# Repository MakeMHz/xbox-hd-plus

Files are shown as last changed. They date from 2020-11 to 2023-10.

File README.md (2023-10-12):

<h1 align="center">
  <br>
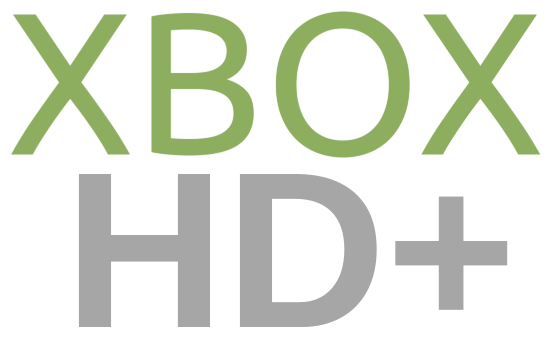
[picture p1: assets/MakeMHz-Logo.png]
XboxHD+
  
  <br>
</h1>
<h4 align="center">The first and only purely digital video output mod for the original Microsoft Xbox.</h4>
<p align="center">
 
 
 
 
</p>
<p align="center">
  <a href="#about">About</a> •
  <a href="#features">Features</a> •
  <a href="#installation">Installation</a> •
  <a href="#software">Software</a> •
  <a href="#hardware">Hardware</a> •
  <a href="#licensing">Licensing</a>
</p>

## About
The first and only purely digital video output mod for the original Microsoft Xbox. Video is captured directly off of the pixel data bus from the GPU, encoded, and sent directly to your HD TV with no added interpolation or frame-buffering for a crystal clear, no added lag, video output.

But pixel-perfect video isn't all the XboxHD+ offers. Audio is captured from the Xbox's digital SPDIF audio and output over the HDMI connector, and with the correct receiver allow for 5.1 Dolby Digital audio on select games.

XboxHD+ has been in development for over a year and fully tested on every board variation and revision.

## Features
XboxHD+ was designed from the ground up to be the best possible solution for your original Xbox.

  *  Pixel perfect digital video. Supports all official Xbox video resolutions. (480i, 480p, 576i, 720P, and 1080i)
  *  Crystal clear digital audio with surround-sound and Dolby Digital pass-through.
  *  Upgradable firmware via our Xbox application for additional future features, bug fixes, etc!
  *  HDMI CEC support.
  *  Completely reversible! 100% no-cut mod.
  *  Optional force 480P. (Force 480i games to run in 480p)
  *  Optional auto anamorphic widescreen for widescreen 480P content. By default, 16:9 480P content will be stretched to fullscreen as the game intended. Avoid the hassle of having to adjust your TV's zoom/aspect ratio when switch between widescreen and none-widescreen 480P games.

## Installation
**Stellar XboxHD+**

[Upgrading to Stellar XboxHD+](https://support.makemhz.com/xbox-hdmi/upgrade/stellar)

[Installation Manual (Stellar XboxHD+ v2 1.0 - 1.5)](https://support.makemhz.com/xbox-hdmi/installation/stellar-xboxhd-1-0)

[Installation Manual (Stellar XboxHD+ v2 1.6)](https://support.makemhz.com/xbox-hdmi/installation/stellar-xboxhd-1-6)

**XboxHD+**

[Installation Manual (XboxHD+ 1.0 - 1.5)](https://support.makemhz.com/xbox-hdmi/installation/xboxhd-1-0)

[Installation Manual (XboxHD+ 1.6)](https://support.makemhz.com/xbox-hdmi/installation/xboxhd-1-6)

**XboxHDMI**

[Installation Manual (XboxHDMI 1.0 - 1.5)](https://support.makemhz.com/xbox-hdmi/installation/xboxhdmi-1-0)

[Installation Manual (XboxHDMI 1.6)](https://support.makemhz.com/xbox-hdmi/installation/xboxhdmi-1-6)

## Software
Configuration and firmware updates are preformed using the XboxHD+ homebrew app. For Stellar XboxHD+ everything is handled via StellarOS.

See [MakeMHz/xbox-hd-plus-app](https://github.com/MakeMHz/xbox-hd-plus-app) (For XboxHD+ installs)

See [MakeMHz/xbox-hdmi-app](https://github.com/MakeMHz/xbox-hdmi-app) (For XboxHDMI installs)

## Hardware
### QSB Fix (1.0/1.1)
[KiCad Project](board/1_0_fix)

### 3D Printed Parts
The XboxHD+ kit includes two 3D printed parts. Parts are designed in Fusion360 and can be downloaded in multiple formats from the links below.

[HDMI Panel](https://raw.githubusercontent.com/MakeMHz/xbox-hd-plus/master/stl/Case%20Filler.stl)

[Board Spacer](https://raw.githubusercontent.com/MakeMHz/xbox-hd-plus/master/stl/Board%20Spacer.stl)

## Licensing
Parts of XboxHD+ are free and open source with plans to release everything else in the near future. Please respect the licenses available in their respective folders.

Hardware is shared under the CERN OHL version 1.2.
 
XboxHD+ configuration app was made with NXDK and is shared under GPLv2.

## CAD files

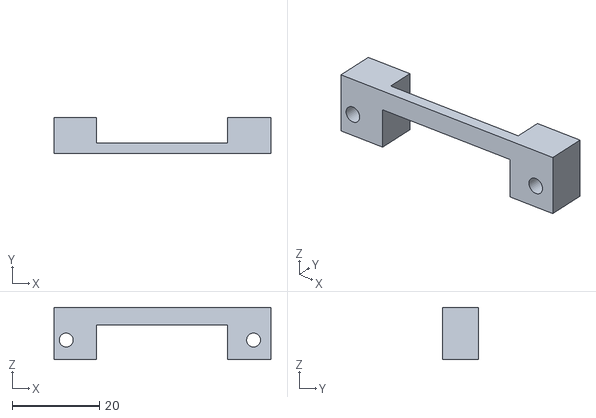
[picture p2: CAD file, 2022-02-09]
stl/Board Spacer.stl
49.8 x 8.20 x 12.0

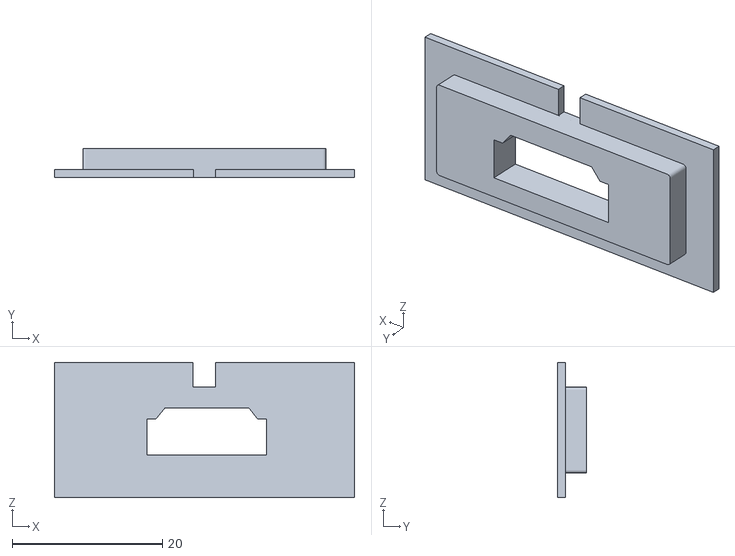
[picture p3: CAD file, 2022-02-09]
stl/Case Filler.stl
40.0 x 3.80 x 18.0

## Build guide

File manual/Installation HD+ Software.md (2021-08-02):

# Installation - XboxHD+ Software
This guide is for the installation of the XboxHD+ software and kernel patch.

## Checklist
- [ ] OpenXenium installed.
  - [ ] Tested and verified that OpenXenium is accessible via network. (Both HTTP and FTP)
- [ ] System is fully working.

### CONTACT SUPPORT IF YOU HAVE ANY QUESTIONS OR CONCERNS!

## Hard Drive Preparation

### Step 1:
Boot console to XeniumOS via the eject button.

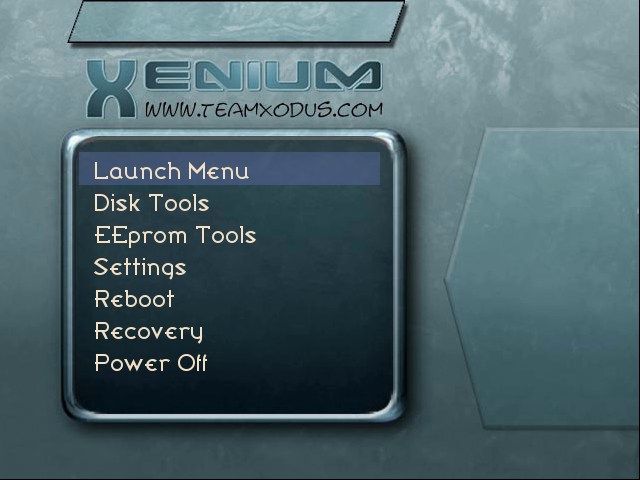
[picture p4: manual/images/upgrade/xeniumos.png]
XeniumOS Boot Screen


### Step 3:
Download the latest XboxHD+ app release.

[Latest Release](https://github.com/MakeMHz/xbox-hd-plus-app/releases/latest)

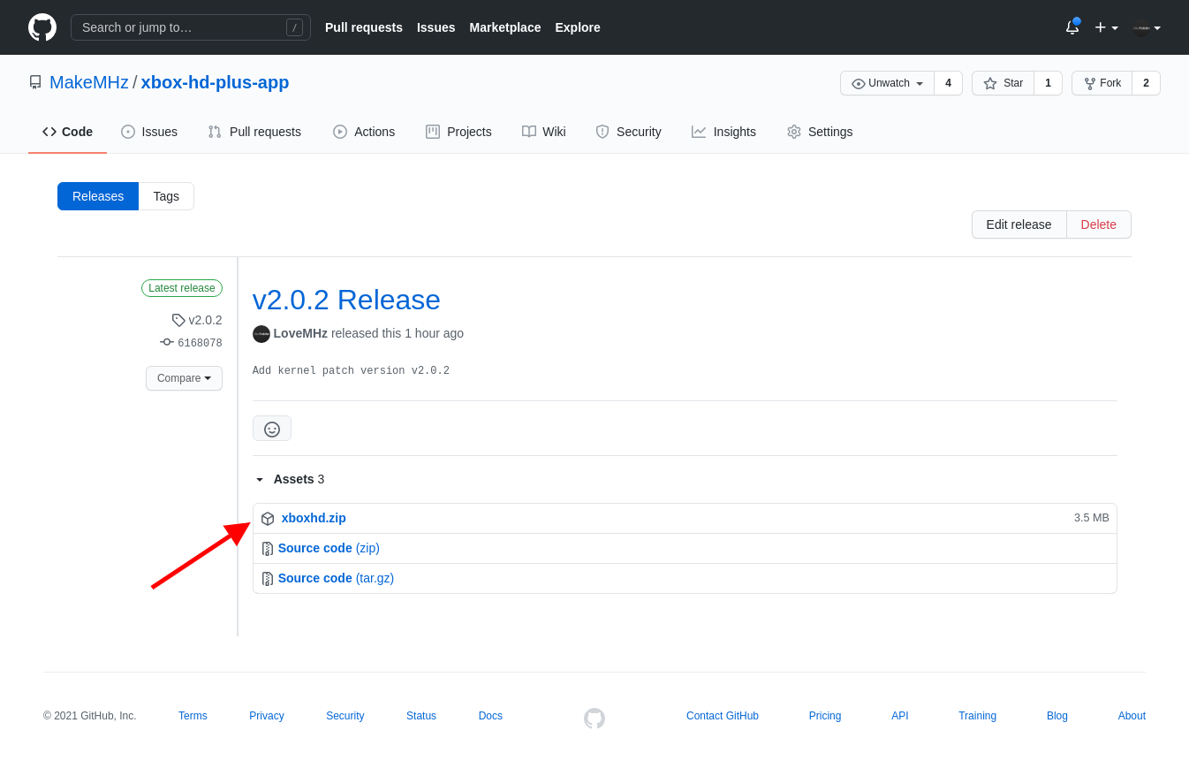
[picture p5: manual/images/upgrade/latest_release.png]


### Step 4:
Extract the files and FTP over contents to the C drive. Files must be placed on the C drive. (Inside of a folder called 'xboxhd' as shown)

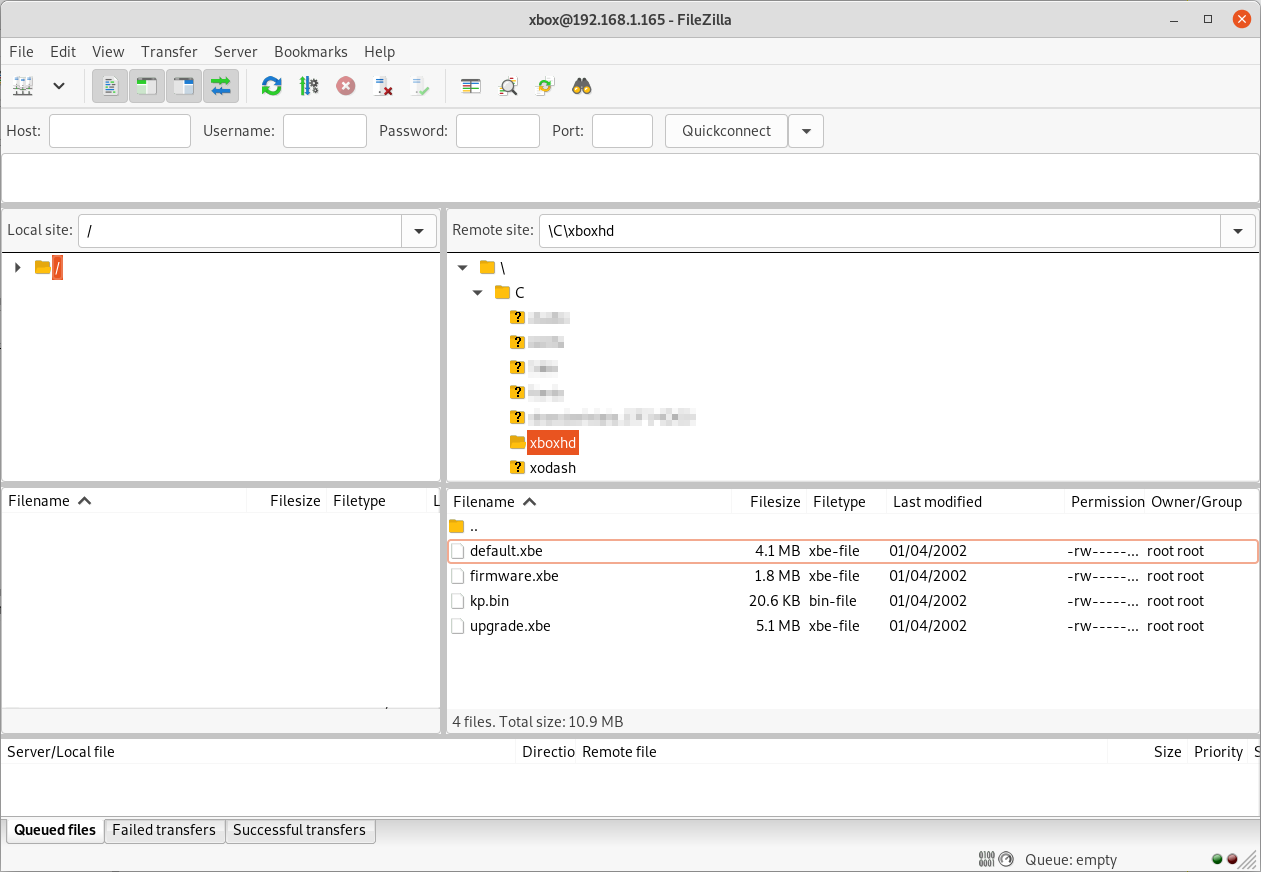
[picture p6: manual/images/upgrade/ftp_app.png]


### Step 5:
Leave Xbox on and continue to the next section.

## Patching BIOS with kpatcher support

### Step 1
Download the latest kpatch IPS file for your BIOS of choice.

[BIOS Patches](/patches/README.md#xbox-kernel-patches-kpatch---xboxhd)

### Step 2
Apply patch to BIOS by following the link to the patching guide for the corresponding BIOS patch. (Due to legal reasons we can not distribute the BIOS files)

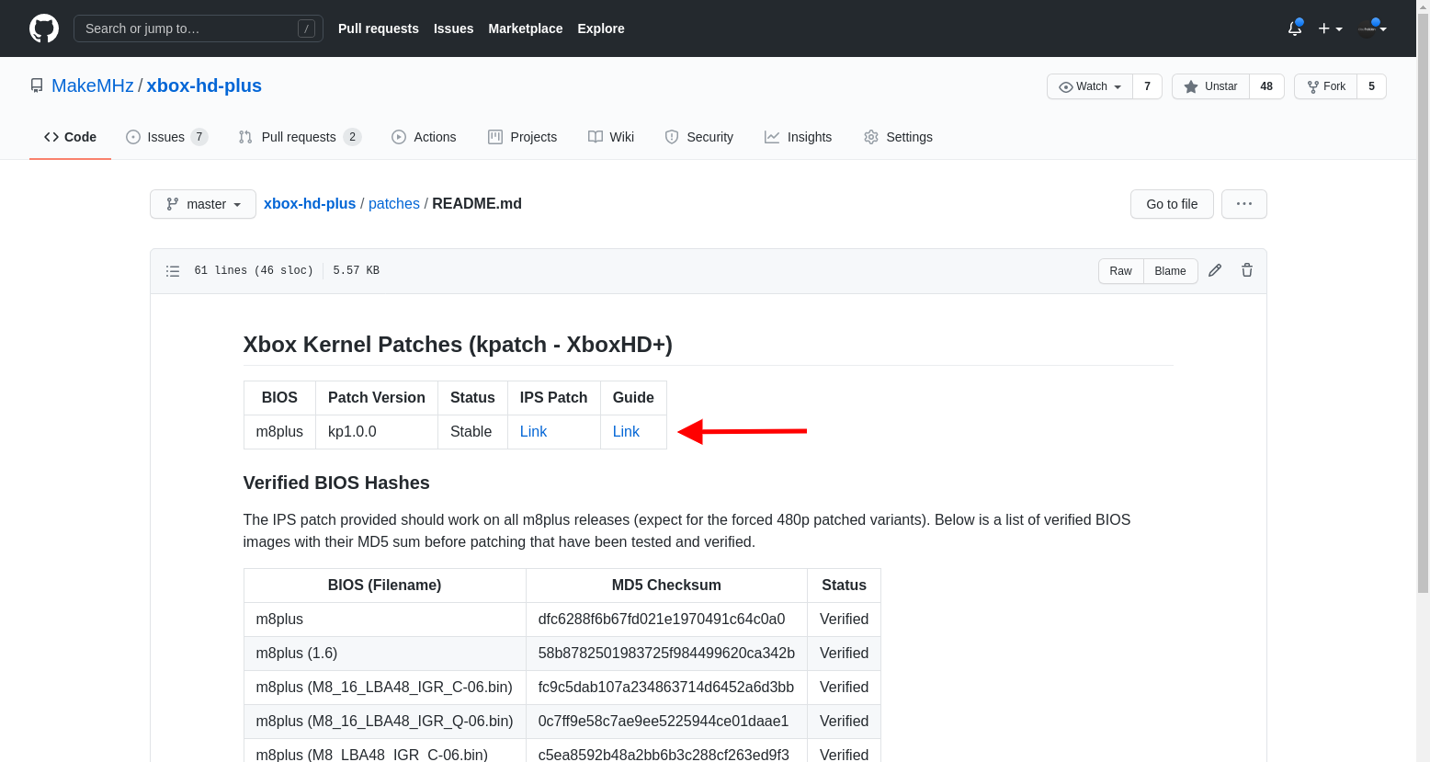
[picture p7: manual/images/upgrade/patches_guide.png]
BIOS Guides


### Step 3
FTP the patched BIOS file over to Xbox. It's recommended to store the BIOS file inside of a folder on the C drive called 'BIOS' for future refrences.

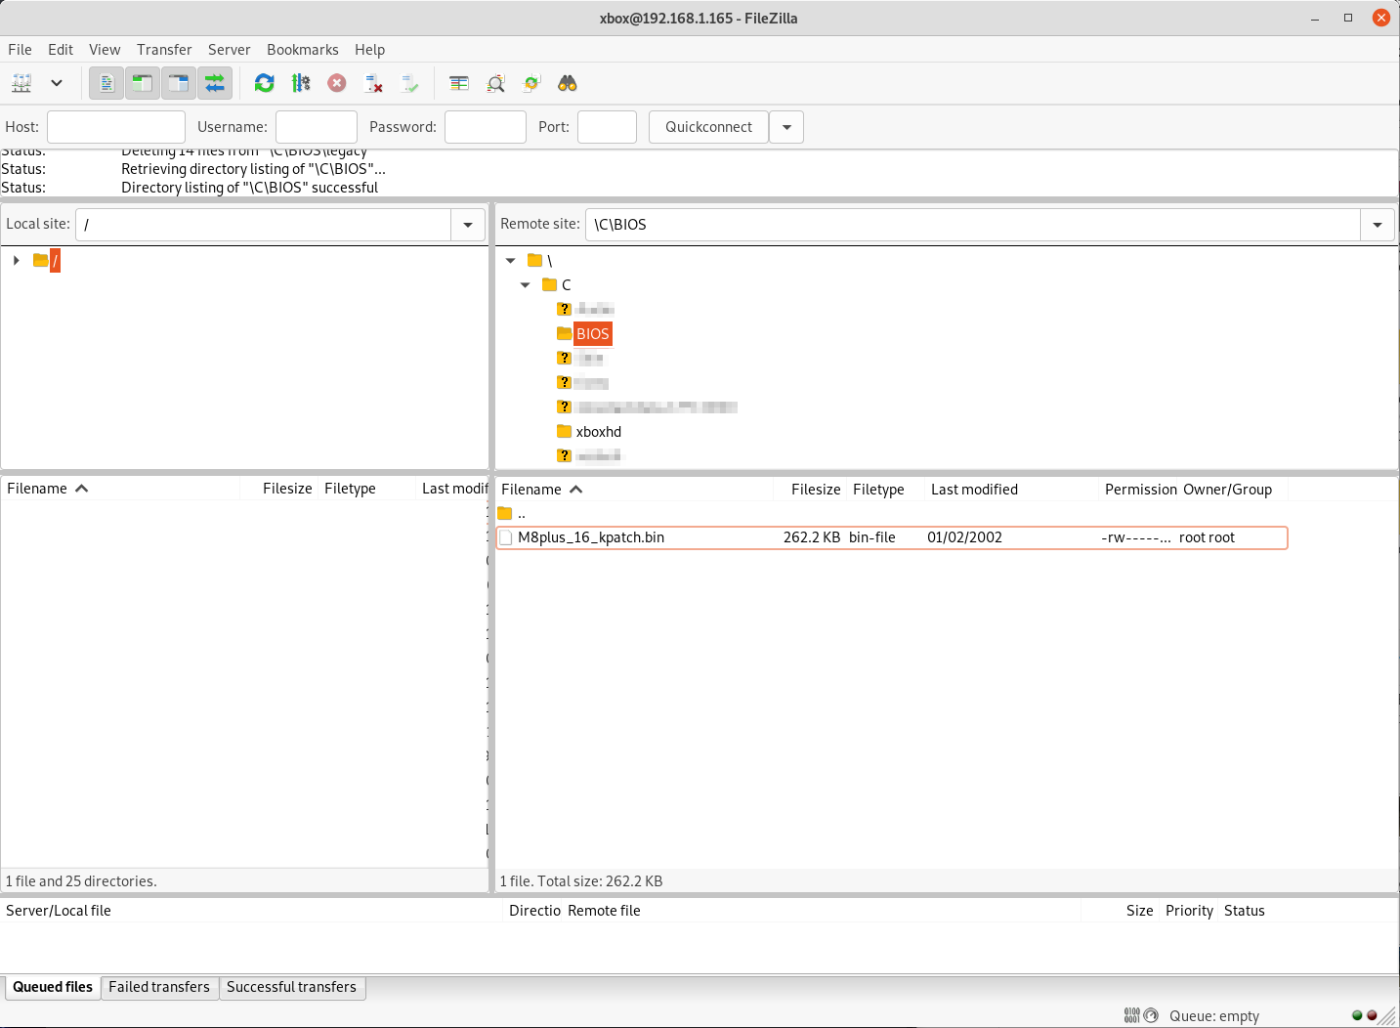
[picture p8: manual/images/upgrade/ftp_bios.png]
FTP BIOS bin file


### Step 4
Flash BIOS.

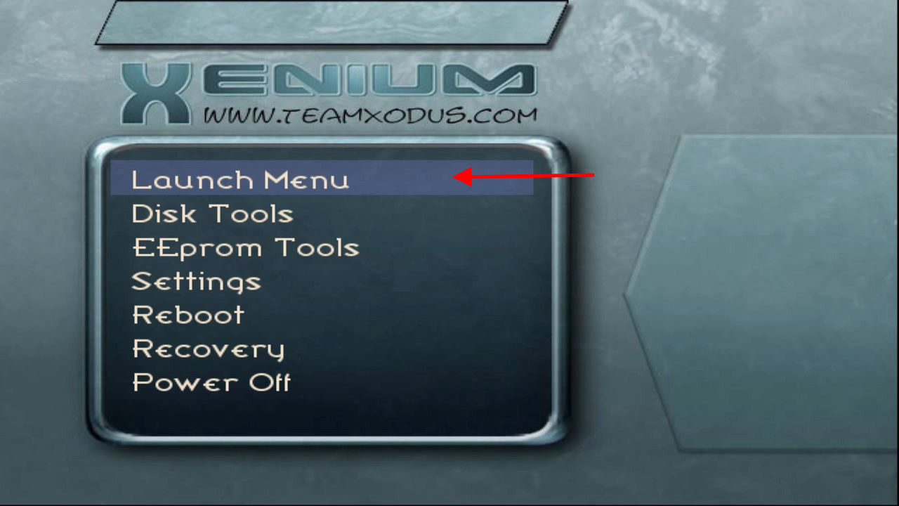
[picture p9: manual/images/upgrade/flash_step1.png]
BIOS Flashing Step 1

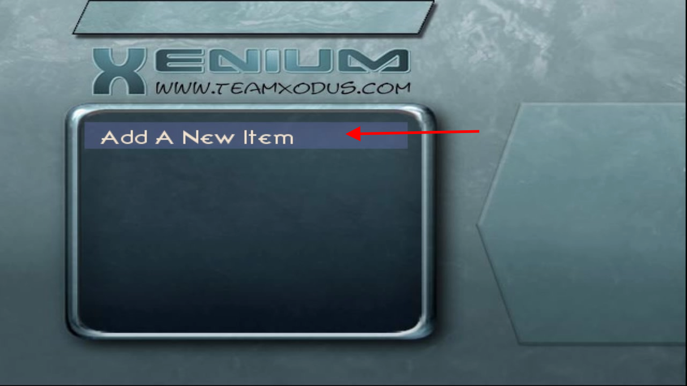
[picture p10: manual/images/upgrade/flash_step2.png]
BIOS Flashing Step 2

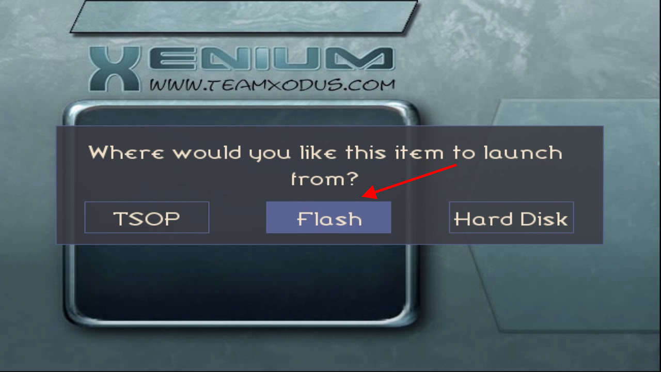
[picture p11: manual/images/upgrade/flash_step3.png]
BIOS Flashing Step 3

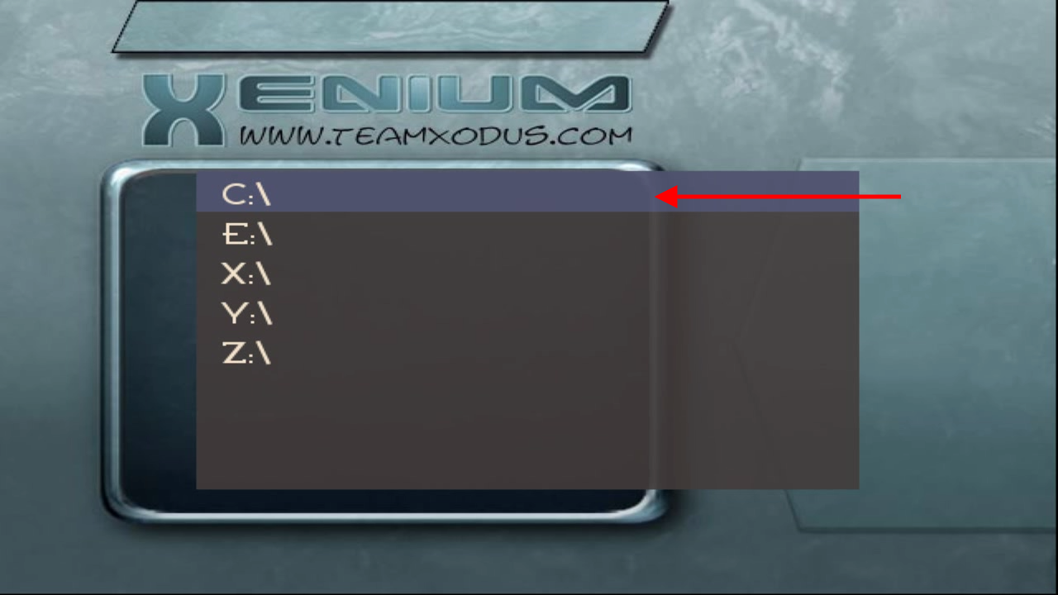
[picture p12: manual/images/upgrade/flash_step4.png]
BIOS Flashing Step 4

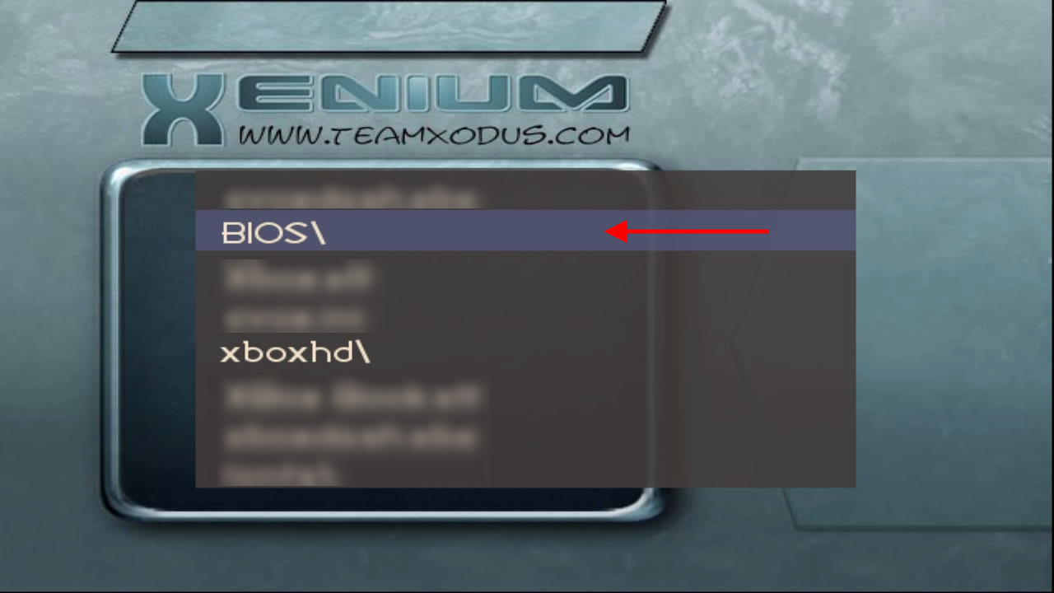
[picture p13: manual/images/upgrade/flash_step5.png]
BIOS Flashing Step 5

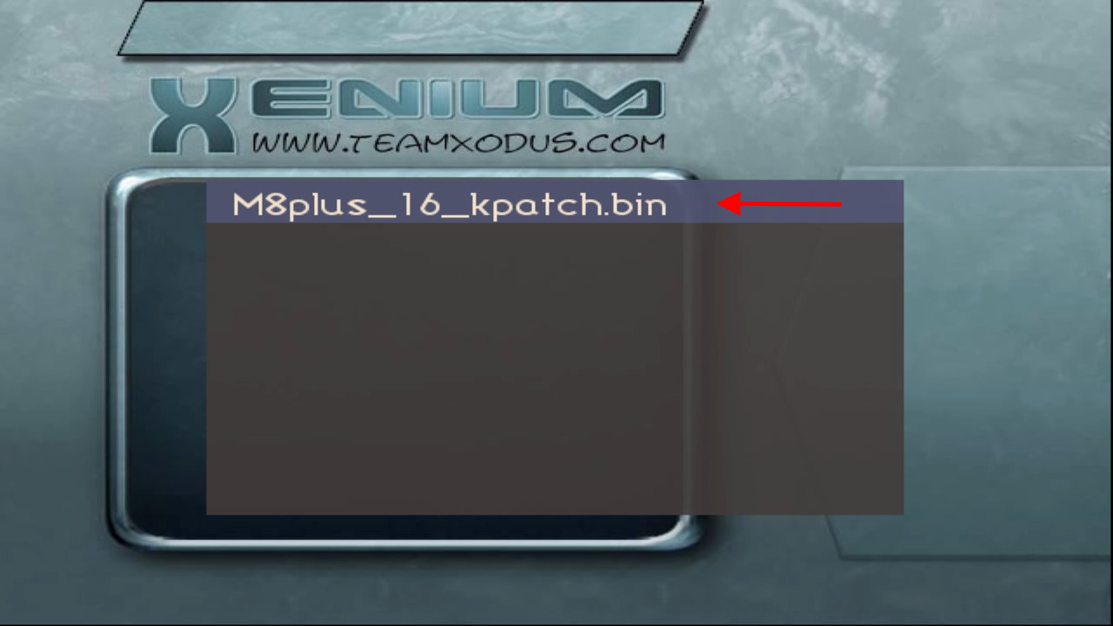
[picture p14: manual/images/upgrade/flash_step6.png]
BIOS Flashing Step 6

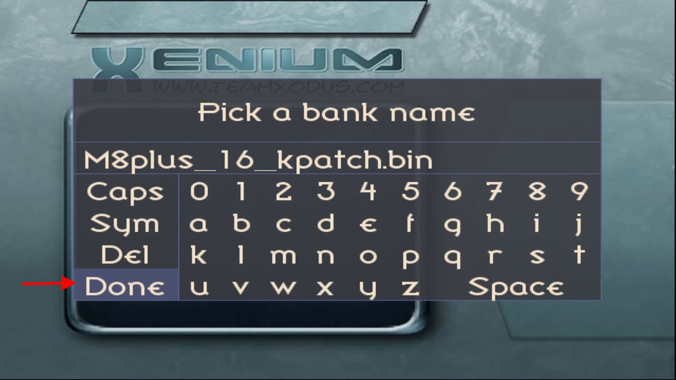
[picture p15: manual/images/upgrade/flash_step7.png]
BIOS Flashing Step 7

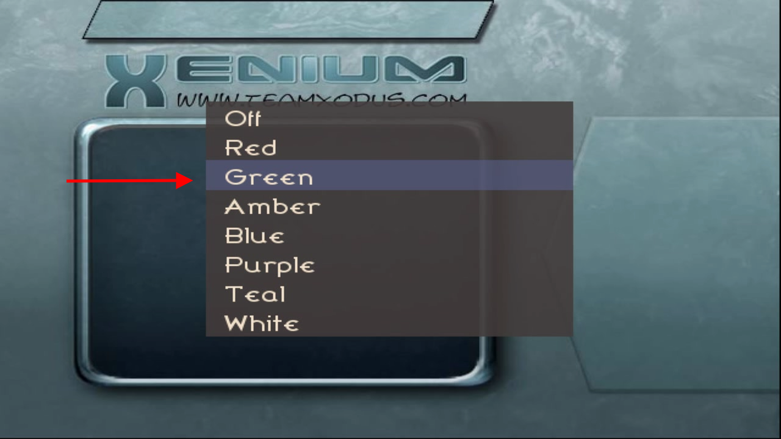
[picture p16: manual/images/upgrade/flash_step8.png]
BIOS Flashing Step 8


### Step 5
Set the newly flashed BIOS as the default BIOS.

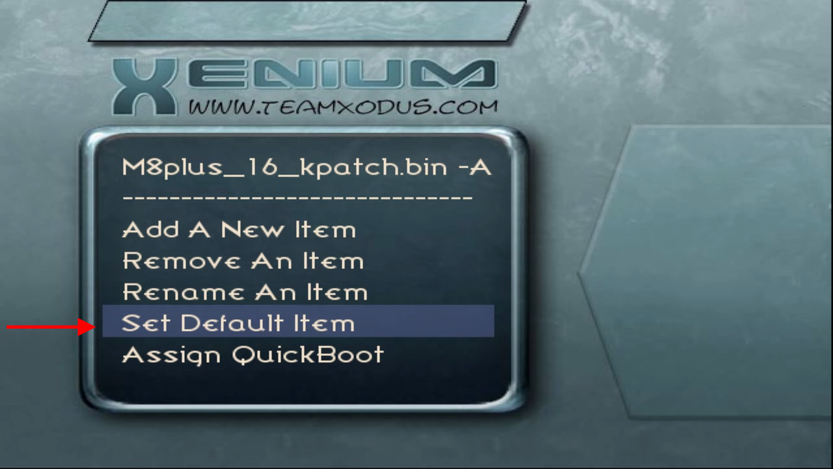
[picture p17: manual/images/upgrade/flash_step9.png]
BIOS Flashing Step 9

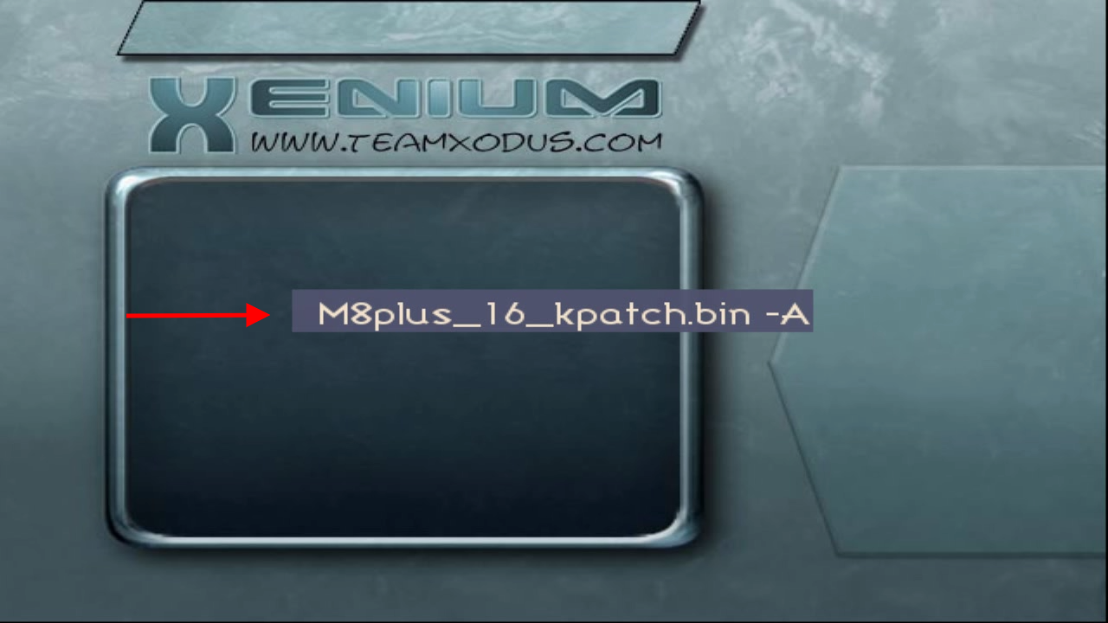
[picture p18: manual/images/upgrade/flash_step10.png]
BIOS Flashing Step 10


### Step 6
Ensure that 'Instant Boot' is enabled. This automatically boot the default BIOS on power up.

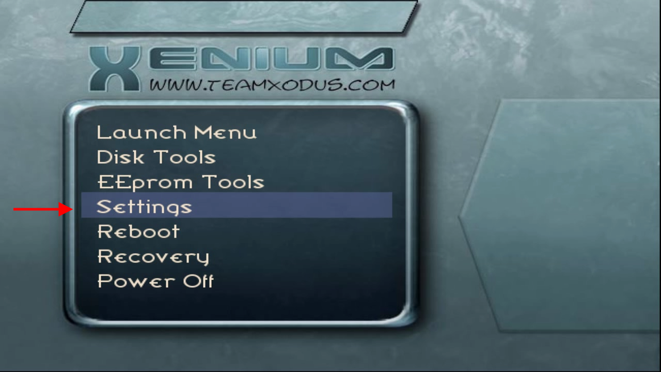
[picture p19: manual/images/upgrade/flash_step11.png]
BIOS Flashing Step 11

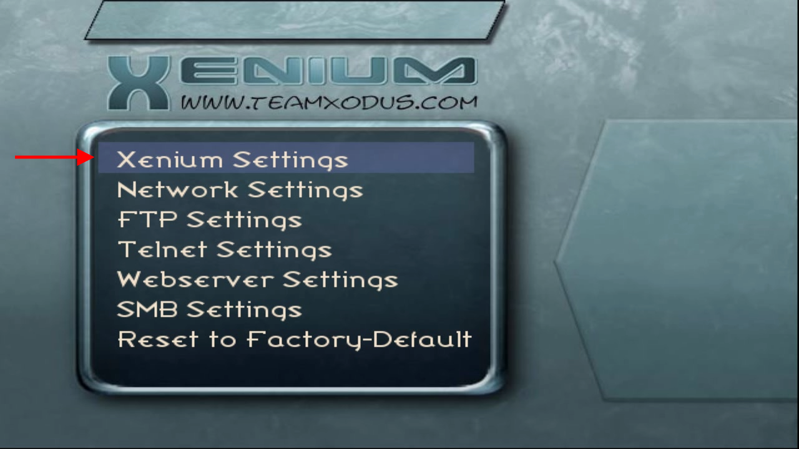
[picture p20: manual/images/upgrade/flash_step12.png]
BIOS Flashing Step 12

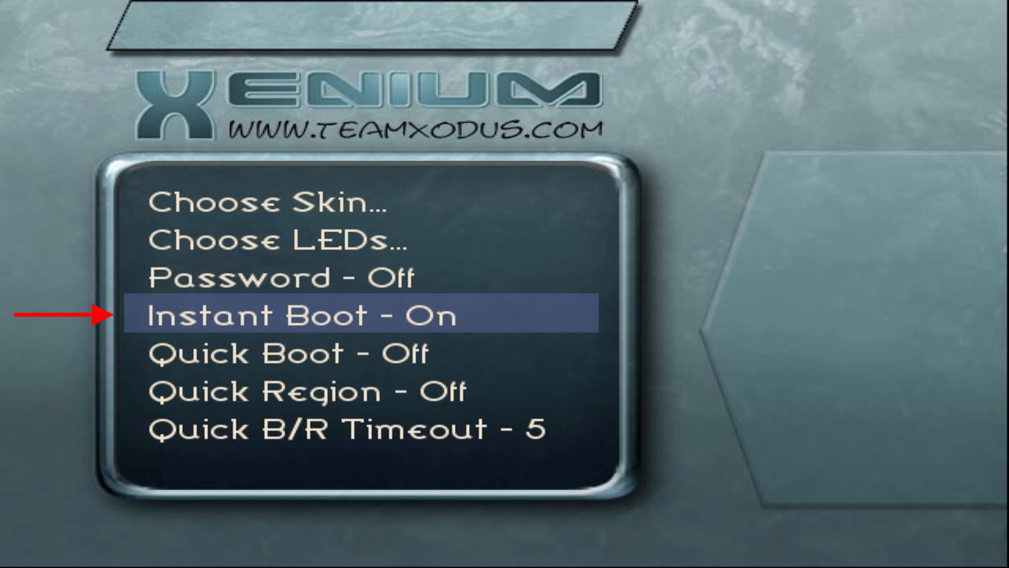
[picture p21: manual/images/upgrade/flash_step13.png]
BIOS Flashing Step 13


## Adding Shortcuts
TODO: Add guides for adding launch shortcuts to C:\xboxhd\default.xbe

## Verification
At this point you can reboot the Xbox. This will boot the patched BIOS.

### Step 1:
Launch the XboxHD+ app. If all went well you should now see the configuration app and text that says 'Kernel patch loader detected'.
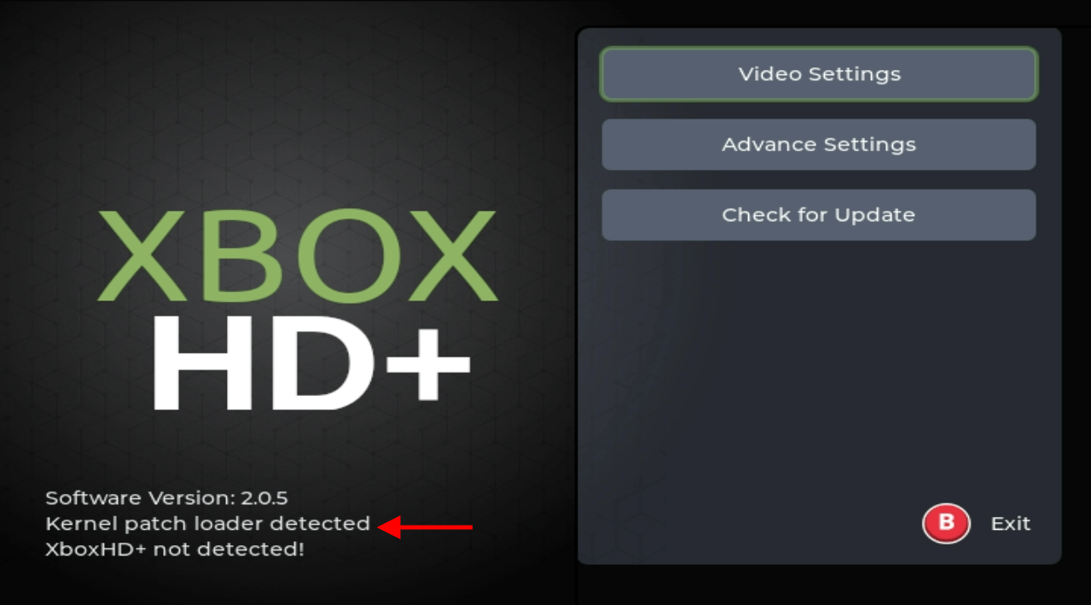
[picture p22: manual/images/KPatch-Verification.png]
Kernel patch installation verification


## All Done
And that's it! Installation of the XboxHD+ kit can now continue.

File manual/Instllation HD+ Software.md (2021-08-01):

# Instllation HD+ Software
This guide is for upgrading existing XboxHDMI, firmware 1.x.x, installs to XboxHD+.

## Checklist
- [ ] OpenXenium installed.
  - [ ] Tested and verified that OpenXenium is accessible via network. (Both HTTP and FTP)
- [ ] System is fully working.

### CONTACT SUPPORT IF YOU HAVE ANY QUESTIONS OR CONCERNS!

## Hard Drive Preparation

### Step 1:
Boot console to XeniumOS via the eject button.

XeniumOS Boot Screen

### Step 3:
Download the latest XboxHD+ app release.

[Latest Release](https://github.com/MakeMHz/xbox-hd-plus-app2/releases/latest)

FTP BIOS bin file

### Step 4:
Extract the files and FTP over contents to the C drive. Files must be placed on the C drive. (Inside of a folder called 'xboxhd' as shown)

XeniumOS Boot Screen

### Step 5:
Leave Xbox on and continue to the next section.

## Patching BIOS with kpatcher support

### Step 1
Download the latest kpatch IPS file for your BIOS of choice.

[BIOS Patches](https://github.com/MakeMHz/xbox-hd-plus/blob/master/patches/README.md)

### Step 2
Apply patch to BIOS by following the link to the patching guide for the corresponding BIOS patch. (Due to legal reasons we can not distribute the BIOS files)

BIOS Guides

### Step 3
FTP the patched BIOS file over to Xbox. It's recommended to store the BIOS file inside of a folder on the C drive called 'BIOS' for future refrences.

FTP BIOS bin file

### Step 4
Flash BIOS.

BIOS Flashing Step 1
BIOS Flashing Step 2
BIOS Flashing Step 3
BIOS Flashing Step 4
BIOS Flashing Step 5
BIOS Flashing Step 6
BIOS Flashing Step 7
BIOS Flashing Step 8

### Step 5
Set the newly flashed BIOS as the default BIOS.

BIOS Flashing Step 9
BIOS Flashing Step 10

### Step 6 (Optional/Recommended)
Ensure that 'Instant Boot' is enabled. This automatically boot the default BIOS on power up.

BIOS Flashing Step 11
BIOS Flashing Step 12
BIOS Flashing Step 13

## Adding Shortcuts
TODO: Add guides for adding shortcuts to C:\xboxhd\default.xbe

## Firmware Update
At this point you can reboot the Xbox. This will boot the patched BIOS.

### Step 1:
Launch the XboxHD+ app.

### Step 2:
Apply update. The update will wait 2 minutes before flashing the firmware update.
**DO NOT TURN OFF THE XBOX** once the front LEDs turn orange. Doing so can/will brick the XboxHDMI/XboxHD+.

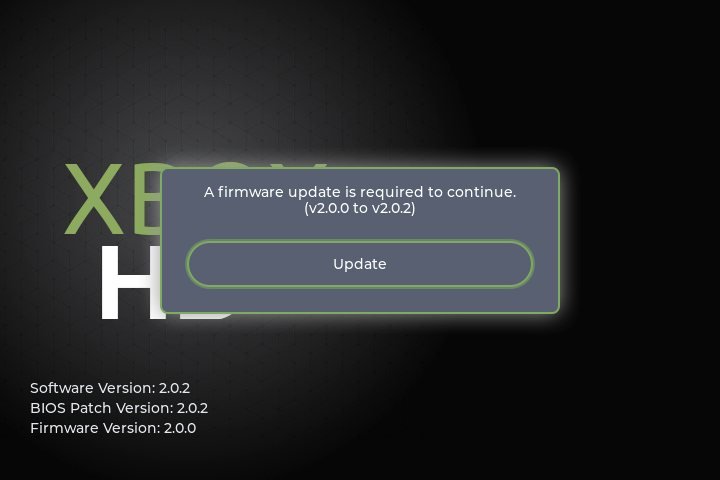
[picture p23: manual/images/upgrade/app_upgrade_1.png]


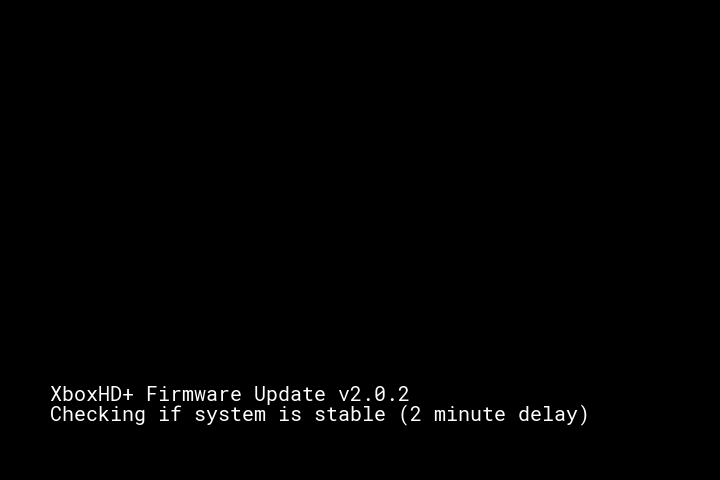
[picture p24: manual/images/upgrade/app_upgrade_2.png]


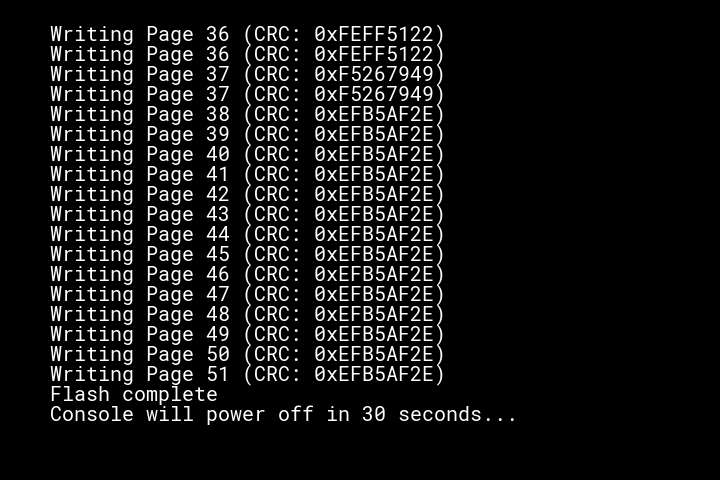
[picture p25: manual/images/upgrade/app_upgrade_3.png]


# Step 3
Repeat by launching the XboxHD+ app again. Depending on the starting firmware you may have to update multiple times.

## All Done
And that's it!

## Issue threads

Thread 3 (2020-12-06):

Resistor R5A8 obstructs "1.0-1.5" flex on 1.2/1.3 motherboards

Redherring32, 2020-12-06:

LoveMHz, 2020-12-06:
Thanks for bringing this over from Discord so it's not lost. This needs to be addressed in the installation manual.

Redherring32, 2020-12-06:
I should note, R5A8 is unpopulated on 1.4 motherboards, so this is exclusive to 1.2/1.3 as far as I know.

LoveMHz, 2021-05-23:
Looks like you're talking about R4A4 and it connects FSADJUST to GND via a resistor, as per the Conexant datasheet. What would be interesting to know is if it's still needed.

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

>  Full-scale adjust control pin. A resistor (RSET) connected between this pin and GND controls the full-scale output current on the analog outputs.

I don't see anything that would suggest it could affect CLK timings, so it might be worth testing with it removed to see that's a viable option instead of adjusting the flex for future runs.

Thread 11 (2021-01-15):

Configurable features saved to eeprom not persisting through power cycles.

chase-cobb, 2021-01-15:
Open the XboxXDMI app, adjust some of the configurable features (widescreen, luma, etc) and back out of the application. If you restart the application before power cycling the adjustments will still be there, but after a power cycle they are lost.

LoveMHz, 2021-01-15:
Fixed in version of 2.0.1 of the firmware.

chase-cobb, 2021-01-15:
Can you leave the ticket open until the firmware is released, for tracking purposes?

Closed 2021-01-15.

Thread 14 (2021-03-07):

Dead or Alive 3 USA widescreen incorrect display

kimbapslice, 2021-03-07:
DOA 3 USA version widescreen is displaying with cropped or shifted to the right. PAL version works correctly. USA is an older software revision so I think the way the actual game handles image output differs.

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

Tested on:
Imaged is cropped on the right side
Xbox 1.4 (ntsc)
XboxHDMI firmware 1.2.1
Kernel Patch 1.3.1 (evox m8plus)
Xbox HDMI software 1.0.3 - all settings are default
Widescreen, 480p disabled, 720p and 1080i enabled
LG tv aspect ratio set to auto/"determined by program"
Aspect ratio reported is 4:3 480p

Compared against:
**Aspect ratio flag seems to be 4:3.**
Xbox 1.0/1.1 stock (ntsc)
Official MS HD Pack
MS stock dashboard (latest)
Widescreen
480p enabled, 720p and 1080i enabled
Widescreen image displays correct when tv set to 16:9, squished when set to auto.
Image is not cropped

LoveMHz, 2021-03-31:
@kimbapslice thank you so much for the detailed issue report. I just wanted to add a note that this issue hasn't been overlooked, we've just been swamped, and I will take a look ASAP.

uberpolka, 2021-05-23:
I don't believe this is XboxHDMI specific. I have seen the same behavior on non-hdmi consoles.
I thought it was an issue with my OSSC settings at first.

480p enabled in the dashboard works correctly.
480p disabled in dashboard with 480p patched bios exhibits the issue.

Again, this was seen before XboxHDMI was released.

dzastsed, 2021-05-23:
I noticed the same issue happening, if you have 480p disabled in dashboard, both eith xboxhdmi modded console and with one, which has force 480p bios and uses component cables

LoveMHz, 2021-05-23:
@uberpolka @dzastsed thanks for the confirmations. In that case, it should be a simple workaround in v2 of the firmware/patch. We're handling mode detection at the kernel level for per-game control since this isn't the only odd case of 480p disabled/720p enabled causing unexpected behavior. Conker: Live and Reloaded, Max Payne (Crash), and Monopoly (Crash) just to name a few.

I'm going to leave this open until the patch is released and tested.

kimbapslice, 2022-05-15:
Working correctly as of 2.1.5. Thanks for fixing this Dustin!

Closed 2022-05-15.

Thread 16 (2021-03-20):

Freeze with 720p dashboards on v1.0/1.1 Motherboards

nightowl3090, 2021-03-20:
Dashboards running at a 720p resolution will lock up and freeze the Xbox (audio stops playing too) 5-10 seconds after initially loading the dashboard. Navigating to less visually complex menus or immediately loading a game can circumvent the issue. But navigating back to the main menu on Xbmc4gamers or letting the Screensaver load on EvolutionX will cause a freeze and lock. Multiple individuals have noted this issue. Removing the makemhz board from a v1.0/1.1 and installing it in a v1.4 motherboard resolves the issue, making it seem that it is specific to those motherboard revisions. Issue persisted with M8+ and IND5003 BIOS. Individuals also reported that the latest M8+ kernal patch does not resolve the issue.

Teamshake, 2021-06-26:
same thing was happening to me to me on a 1.0 board.  i thought there was something wrong with the xbox board so i ended up moving the hdmi mod to a different xbox.  i should have checked here first.

robbiejmsn, 2021-06-26:
Same on mine too. Thought it was my hdd about to kick the bucket.

LoveMHz, 2021-06-26:
Often the case is unnecessarily long wires or bad capacitors causing noise to lock up the GPU. This is covered in part in our last update here. https://makemhz.com/blogs/news/makemhz-and-xboxhd-update

In other cases, it seems to 'pre-coma' related or due to the CPU upgrade mod. If you believe the issue is not related to long wires or bad capacitors then please reach out to support@makemhz.com so we can work out the issue as the new QSB design should help with any signal noise issues (even those with poor/failing capacitors).

Teamshake, 2021-06-27:
just a note as ive removed mine from the 1.0 console (stock cpu) so not able to troubleshoot issue.  i had used the wire length from the install guide and i used the same wires when i transplanted it to a 1.4 board which is working.  only thing new was the flex cable as i ordered are replacement.  also the console had been recently recapped.  i did not replace the smd caps, only the through hole, so i guess it could be one of those smd caps causing an issue.

Justawajz, 2022-05-22:
Any update to this?  Just installed a HD+ in a 1.0 with new caps and also having this issue.

robbiejmsn, 2022-05-23:
Yes, it's being tested in beta and will be implemented in an update shortly.

LoveMHz, 2022-06-10:
Resolved in FW2.1.x

Closed 2022-06-10.

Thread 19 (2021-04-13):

Conker: Live & Reloaded Overscan Issue

TheLegendOfXela, 2021-04-13:
When 480p is turned off, and 480p is forced by the edited bios, Conker still has overscan bars.

TheLegendOfXela, 2021-04-13:
I’m a buffoon

dracc, 2021-04-13:
> I’m a buffoon

How so? @TheLegendOfXela

TheLegendOfXela, 2021-04-13:
> > I’m a buffoon
>
> How so? @TheLegendOfXela

According to 2 other users on the discord, Conker works without overscan bars.

Closed 2021-04-13.

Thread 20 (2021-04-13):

1.6 xbox with 1.3.2 patch shows 55hz refresh choppy video output

kimbapslice, 2021-04-13:
Setup:
Xbox 1.6, xboxhdmi, otherwise stock
Firmware 1.2.2
Kernel Patch 1.3.2 built from m8plus (M8_16_LBA48_IGR_Q-06.bin) | 0c7ff9e58c7ae9ee5225944ce01daae1
MS Dashboard options 480p off, 720p on, 1080i on, digital audio all enabled

When hooked up to my TCL 4k 43s515, the opening bios screen and in game (Panzer Dragoon Orta USA) stutters and shows 55hz refresh.
Running stock bios and "stock" evox8plus 1.6 video does not glitch. When hooked up to my ancient LG 1080p 55LV9500-UA, patched bios appears better but the motion of the graphics doesn't seem as smooth (ie not 60hz).

1.4 xboxhdmi, firmware 1.2.1, running evox8+ lba48 igr q 06 patch 1.3.2 on the TCL 4K shows 60hz and bios opening and in game seems to be running normally.

Runwave87, 2021-04-13:
Setup:
XBOX 1.6, xboxhdmi 1.4 with firmware 1.2.2, openxenium, hdd with sata adapter. Kernel patch 1.3.2. Widescreen, 480p off, 720p on, 1080i off.
Samsung ln46b500p3fxza.
Stock m8+ bios will show xbox splash boot screen, dashboard at 720p good no audio glitches.
Patched bios will not show xbox splash boot screen, black screen until dashboard showing mode not supported.  Dashboard works fine at 720p , most games give black screen unless 720p title. Openxenium display works fine.

Same tv has zero issues with 1.0 system with xboxhdmi firmware 1.0.0 and patch 1.3.1.

1.6 system with sharp lc-40le830u will show xbox splash screen at 56hz, but at dash audio will cut out with tv saying unsupported audio. Halo will boot but audio cuts out. System acts normal with stock m8+ bios.

1.0 system system works fine with this TV with 1.3.1 patched bios

LoveMHz, 2022-06-10:
Resolved in FW2.1.x

Closed 2022-06-10.

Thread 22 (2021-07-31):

Forza Motorsport (USA) (En,Ja,Fr,De,Es,It,Pt,Zh,Ko) (v1.70) - Black Screen

LoveMHz, 2021-07-31:
Forza Motorsport (USA) launches to a black screen. I've confirmed this on a 1.6 system and it's been reported on a 1.1 and a 1.2 system too.

Firmware Version: 2.0.5

LoveMHz, 2021-07-31:
Well, that was a fun rabbit hole to go down! After messing around I realized very quickly that I was still getting the black screen even with a stock BIOS.

Then I came across this forum post detailing the same issue with a workaround. And it works!
```
Load up MSdash and switch language to any other. Then switch off and on again and go back to ms dash and select original language. Then restart with Forza.
Worked for me first time with HDD and DVD backups
Good Luck.
```
https://forums.afterdawn.com/threads/359980/#post-2285775

This could possibly be an issue related to how the HD+ patch handles the EEPROM config or a game issue. I'm going to leave this issue open until v2.1 is released (which removes the EEPROM workaround for widescreen detection).

HelicopterP, 2021-07-31:
I don't think this is related to Xboxhdmi at all. I had this problem on Xbox 1.6 with EvoxM8 and component cable.

dzastsed, 2021-08-01:
second that, had this issue with my 1.0 with iND bios and component, and following those steps fixed the issue.

Closed 2021-08-01.

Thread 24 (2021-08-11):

1.4 Xbox with kpatch 1.0.x m8plus bios displays ridiculous CPU temps in xbmc4xbox dashboard

dzastsed, 2021-08-11:
Noticed this issue on both kpatch 1.0.0 and 1.0.1 bioses.
Right after starting up the dashboard, it will display CPU temperature in 1k+ degrees Celsius range. If you switch between skins (for example, project mayhem 3 to confluence lite), temperatures will display correctly, but if you re-start the dashboard again, they will be displayed wrongly again. When testing this with earlier patched bios, such as iND5003 1.4.3, they get displayed correctly from the beginning.
Exact dashboard version and system specs: XBMC4XBOX 3.5.3-r33027, 1.4 system with XBOXHDMI board on 2.0.5 firmware
some pictures:
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

LoveMHz, 2021-08-11:
More than likely just a bug in XBMC.

The GetCPUTempInternal() function [here](https://github.com/svn2github/xbmc4xbox/blob/bb23d016a0c236ca3ee658bb3c0b527e4f86d655/tags/3.5-rc2/xbmc/utils/FanController.cpp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) is very suspect. Direct I/O calls outside of the kernel _should_ be wrapped in KeEnterCriticalRegion/KeLeaveCriticalRegion(), especially since the application is multi-threaded. Additionally, it appears that on 1.6 systems it's just reading the temp from the SMC over the SMBus and should just be calling the HalReadSMBusValue() kernel function instead.

If that's the case then it would have to be corrected inside of the application. None official software has a **very** low chance of having a workaround implemented in our kernel patches. (Not to mention the complexity of targeting all of the different builds)

I'll circle back around to this later, but if someone wants to reimplement CFanController::GetCPUTempInternal() correctly to see if it fixes the issue then would be much appreciated!

LoveMHz, 2022-06-10:
Closing this as it's outside the scope of the HD+. Notes have been left on what can be done to fix the issue inside of XBMC's codebase.

AR1972, 2024-02-13:
XBMC appeared to be going around the kernel to read CPU temps, switching to HalReadSMBusValue() fixed this issue for me, side benefits are that you don't have to wait for 10 samples to get a CPU temp on the 1.6 Xbox.
`void CFanController::GetCPUTempInternal()
{
  unsigned long temp;

  if (!bIs16Box)
  {
	HalReadSMBusValue(0x98, 0x01, FALSE, (LPBYTE)&temp);
  }
  else
  {
	//1.6. Read SMC instead
	HalReadSMBusValue(PIC_ADDRESS, 0x09, FALSE, (LPBYTE)&temp);
  }
  cpuTemp = CTemperature::CreateFromCelsius((double)temp);
}`

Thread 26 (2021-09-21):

Stereo Only Audio

Nomar383, 2021-09-21:
I have a v1.0 mobo with an XboxHD+ freshly installed. I'm using the M8+ BIOS with the latest kernel patch and HD+ App installed. Whether I have the HD+ App set audio to "Compatibility" or "Auto", I cannot get 5.1 audio to work. I am only getting stereo audio in game and in dashboard.

If I use the same BIOS without the HD+ kernel patch, I can set the audio in the dashboard and it saves my settings and plays 5.1 audio in game.

Kobeskillz, 2022-01-31:
I'm having the same issue! It's so frustrating.

Nomar383, 2022-01-31:
Yeah, I’ve been waiting since September without an update of any kind, as you can see. Seems like a low priority unfortunately

LoveMHz, 2022-01-31:
Just a heads up/warning. Commentary, anything that doesn't contribute to the issue, will be removed.

The issue is being looked into.

KylJoy, 2022-02-03:
Me also.

KylJoy, 2022-02-03:
I am also experiencing this issue with same setup.

Commander1024, 2022-02-03:
This is btw. an issue tracker. Not a democratic vot to force someone fix things. This issue is know and being worked on currently. That's why it exists. Contributing additional information is wanted. Adding pressure on Dustin by complaining doesn't solve anything.
Its also not an eventually coming up issue. Every HD+ with 2.x firmware is affected by this bug.

Kobeskillz, 2022-02-03:
> This is btw. an issue tracker. Not a democratic vot to force someone fix things. This issue is know and being worked on currently. That's why it exists. Contributing additional information is wanted. Adding pressure on Dustin by complaining doesn't solve anything. Its also not an eventually coming up issue. Every HD+ with 2.x firmware is affected by this bug.

My bad. Sorry for complaining that Dolby Digital one of the main features of the xbox does not work on this mod we paid money for. Pressure should be applied. Sorry that's how it works. You sell a product that does not list a main feature broken then you should get pressure to fix it.

Complaining about people complaining about a broken feature in a product we paid hard earn money for is bad. Is ok lets sweep this under the rug and i'll wait for them to maybe or maybe not fix it.

LoveMHz, 2022-06-10:
Resolved in FW2.1.x

Closed 2022-06-10.

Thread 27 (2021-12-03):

no picture after installation

peewee82, 2021-12-03:
I have the following problem, after the installation a blue led flashes and no picture appears.
When I pull out the hdmi cable and plug it in again, a picture appears and a green LED lights up continuously, but the blue one continues to flash.
I am sure that I didn’t make any mistakes during the installation and have checked it several times.
What does the blinking of the blue led mean?
I also miss a biospatch for BIOS, which support f and g partitions.

I used latest patches for XBOXHD+ on a 1.4 XBOX witch ALADDIN chip and standard M8Plus BIOS (checksum fits).

In your tutorial you wrote, I have to solder to 1V8 point. But were is it, at revision 5b of the board???

Redherring32, 2021-12-04:
XboxHD+ doesn't need the 1V8 wire, I assume you're reading the XboxHDMI guide, as for the blue LED blinking, that's normal behavior.

It also sounds like your cable is misbehaving, I would recommend trying another, some cables are a but iffy.

peewee82, 2021-12-04:
Thanks for your fast reply. No, i looked in the correct tutorial. Maybe its wrong written in it? You can find that information on picture and written down in the tut itself.
I tried 3 different TV (Sony, Panasonic, Medion) and 3 different cables. The effect is the same. All three cables are Higspeed 2.1 HDMI Cables. I dont know, what i can try more...

LoveMHz, 2021-12-29:
This repo is not for installation troubleshooting. Please join our Discord server where we can assist you in real-time.
https://discord.gg/9YcuDpY

Closed 2021-12-29.

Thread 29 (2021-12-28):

Original XBOX HDMI board for 1.6 xbox

Waterrat26, 2021-12-28:
Hi I've finally installed this board, all went well, it boots and the xbox loading screen comes on with no audio or visual issues. But once it goes onto the XBMC page i here static??? So I resoldered the cables, just to check connecttions but no luck.

LoveMHz, 2021-12-29:
This repo is not for installation troubleshooting. Please join our Discord server where we can assist you in real-time.

https://discord.gg/9YcuDpY

Closed 2021-12-29.

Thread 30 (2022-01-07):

Console 5 Capacitor fitment issue for V1.0 revision

crispycritter911, 2022-01-07:
I've recapped the mother board and power supply of a v1.0 motherboard. The capacitor located at C5A3 is a 10v 680uF capacitor. It interferes with the HD+ motherboard. I had to shave the HD+ board down carefully with a file and bend the capacitor legs to fit. I'd suggest checking fitment of the capacitor and possibly leave the legs a little bit longer to clear the board or find a different capacitor to replace it. I'll email the person at console5 and inform him too.

LoveMHz, 2022-01-07:
Can you share a picture? I've used the kits before and haven't run into any issues.

crispycritter911, 2022-01-07:
I've reached out to Luke from Console5,  he plans on revising the capacitor in his kits and send me a replacement one.
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

crispycritter911, 2022-01-20:
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

crispycritter911, 2022-01-20:
Check the capacitor voltage. The original one sent was 16 volts at 10mm diameter where as the smaller one was 10 volts and only 8mm in diameter

Closed 2022-01-20.

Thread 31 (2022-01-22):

Issues and new BIOS MD5

L10N37, 2022-01-22:
Hi guys, just a few things here :)

Guide has not being updated in regards to the 1v8 point, this isn't on the HDMI PCB ...it's skipped on the installation, but it's on the guide.

Guide still says to install legacy patch, but there's the new XBOXHD+ kernel patch at the top of the patches page.

XBMC is showing a CPU temp of 1075 degrees, it doesn't do this unless the XBOXHD+ FW folder is installed and the FW is active. It was showing the system idling at ~49 degrees prior.

The XBOX HD+ app crashes upon exit, no matter where it's launched from (on both the BIOS's im about to mention)

This isn't really *your issue* but i feel it should be mentioned: The M8 Plus BIOS (MD5: dfc6288f6b67fd021e1970491c64c0a0) listed doesn't support LBA48, so large hard drives are out of the question.  I found one with LBA48 V3 in the TruHexen2020 engineering discs BIOS folder, it's MD5 is   < 94acfb5b4ddd81515386e733ea0020f3 >

Finally, the kernel patch seems to kill the ability to launch the rocky5 extras disc at launch (my preferred way of XBMC installation, as it's hassle free and super simple).  I can still launch it once a dash is launched, but it will not launch at boot anymore for some reason.

L10N37, 2022-01-23:
https://imgur.com/gallery/BA2mfll

here's the temp
and a tiny bit of area on the top, the entire image needs to be shifted up a little

dzastsed, 2022-01-23:
https://github.com/MakeMHz/xbox-hd-plus/issues/24

L10N37, 2022-01-23:
I'm not too concerned about the temp.
the image wasn't shifted down with the original BIOS that I used but that didn't have the LBA48 so I had to switch out. Any chance of a fix for the BIOS mentioned above (shared the hash) so that the image is moved up a little ?? or a feature in the app to allow manual shifting on the X and Y axis ?

dzastsed, 2022-01-23:
shifted down image issue is known as well, and will be fixed in next bios update according to dustin (a side effect of upscaling or something like that). if you don't like it you can disable upscaling by setting video out to 480p in xboxhd+ settings

L10N37, 2022-01-23:
yeah I thought this may have happened after I locked 720P.
no worries. Thanks for the heads up :)

catogtp, 2022-02-24:
"_This isn't really your issue but i feel it should be mentioned: The M8 Plus BIOS (MD5: dfc6288f6b67fd021e1970491c64c0a0) listed doesn't support LBA48, so large hard drives are out of the question._ "

If you open any vanilla M8 in evtool and then save it as a new bios.bin file, the v3 LBA48 patch is added automatically.

Closed 2022-06-10.

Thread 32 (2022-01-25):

Stereo only!!! Dolby Digital broken. Not working most of the time.

Kobeskillz, 2022-01-25:
Hey guys this is driving me absolutely insane. The audio only comes out in stereo no matter what i do. I've tested every single thing for hours and i might get Dolby Digital 1 out of 10-15 tries. I changed wires and tested everything. My Receiver is a denon so it can handle simple dolby which i got before the mod with optical. Please help.

carlocgc, 2022-01-31:
Duplicate of #26

Kobeskillz, 2022-01-31:
Yeah it's a duplicated but i was told to post it here. Just wanna make sure it doesn't get missed it's such a nightmare dealing with this issue.

LoveMHz, 2022-01-31:
Duplicate of #26

Closed 2022-01-31.

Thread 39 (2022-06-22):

PAL mode does not work, system locked to NTSC

fanXbox, 2022-06-22:
I am happy with the new firmware version 2.1.10, which has solved many problems.
But I must point out that it is not possible to switch from NTSC mode to PAL mode (and with some games "Prince of Persia: Warrior Within" the localization does not work correctly), even if you do the switch several times with Enigmah and verify that the EEPROM is actually set in PAL mode.
I was able to set the PAL mode only by deleting the "kp.bin" file, but the video output is squeezed sideways, while if the monitor is set to "fit image", the image is shifted and enlarged.

fanXbox, 2025-04-01:
After installing stellar and updating to version 1.7.2, I was finally able to enjoy PAL games with the correct localization of dubbing.
However, I must point out that some titles such as "Halo 2" have a problem with the correct hooking of dialogues (they start at different times than normal or tend to overlap slightly), I noticed that on the original dashboard and with Stellar set to PAL mode, the 60 Hz mode is not enabled (in fact, the option is not even present in "Stellar OS"); I don't know if this affects the correct synchronization of dialogues, but usually this problem with dialogues (on this generation of consoles) occurs when NTSC games are run in PAL mode or vice versa.

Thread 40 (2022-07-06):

Red Grain Xbox 1.6

carlblackwell, 2022-07-06:
I have the latest version 2.1.10 and I experience what looks to be a red grain on certain surfaces within 720p mode that I do not experience when in 480p.

kimbapslice, 2022-09-02:
I am experiencing the same issue. On an xbox v1.6 with xboxhdmi firmware 2.10.0. Only occurs when 720p upscale is enabled and only during certain games. Repeatable with Capcom VS SNK 2 and Jet Grind/Set Radio Future.

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

ChaoticWeaponry, 2023-08-30:
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

Same issue on another 1.6. Set to 720p and running the latest firmware (I believe 2.2 now)
I have not tried running on 480p, but it definitely has a grain issue (and sometimes scan lines that move up and down)

subierekt, 2023-08-30:
This is caused by improper flex cable soldering. GitHub isn’t really the place for troubleshooting, you should check out the makemhz discord.

ChaoticWeaponry, 2023-08-30:
> This is caused by improper flex cable soldering. GitHub isn’t really the place for troubleshooting, you should check out the makemhz discord.

I'll give it another go then. The joints looked fine on the first and second attempt, measured 33ohms from one side of the resistor to the flex, though maybe was just measuring the solder and not the contact to the pad. Thanks!

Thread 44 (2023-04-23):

New Project Stellar and XBOX HD+ v2 install

ejlg87, 2023-04-23:
Greetings, hoping to get some guidance. Please see attached photos. I can’t seem to fix this issue and I’m not sure if it’s software related or just bad luck. XBOX 1.0
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

LoveMHz, 2023-04-23:
This repo is not for installation troubleshooting. Please join our Discord server where we can assist you in real-time.
https://discord.gg/9YcuDpY

Closed 2023-04-23.

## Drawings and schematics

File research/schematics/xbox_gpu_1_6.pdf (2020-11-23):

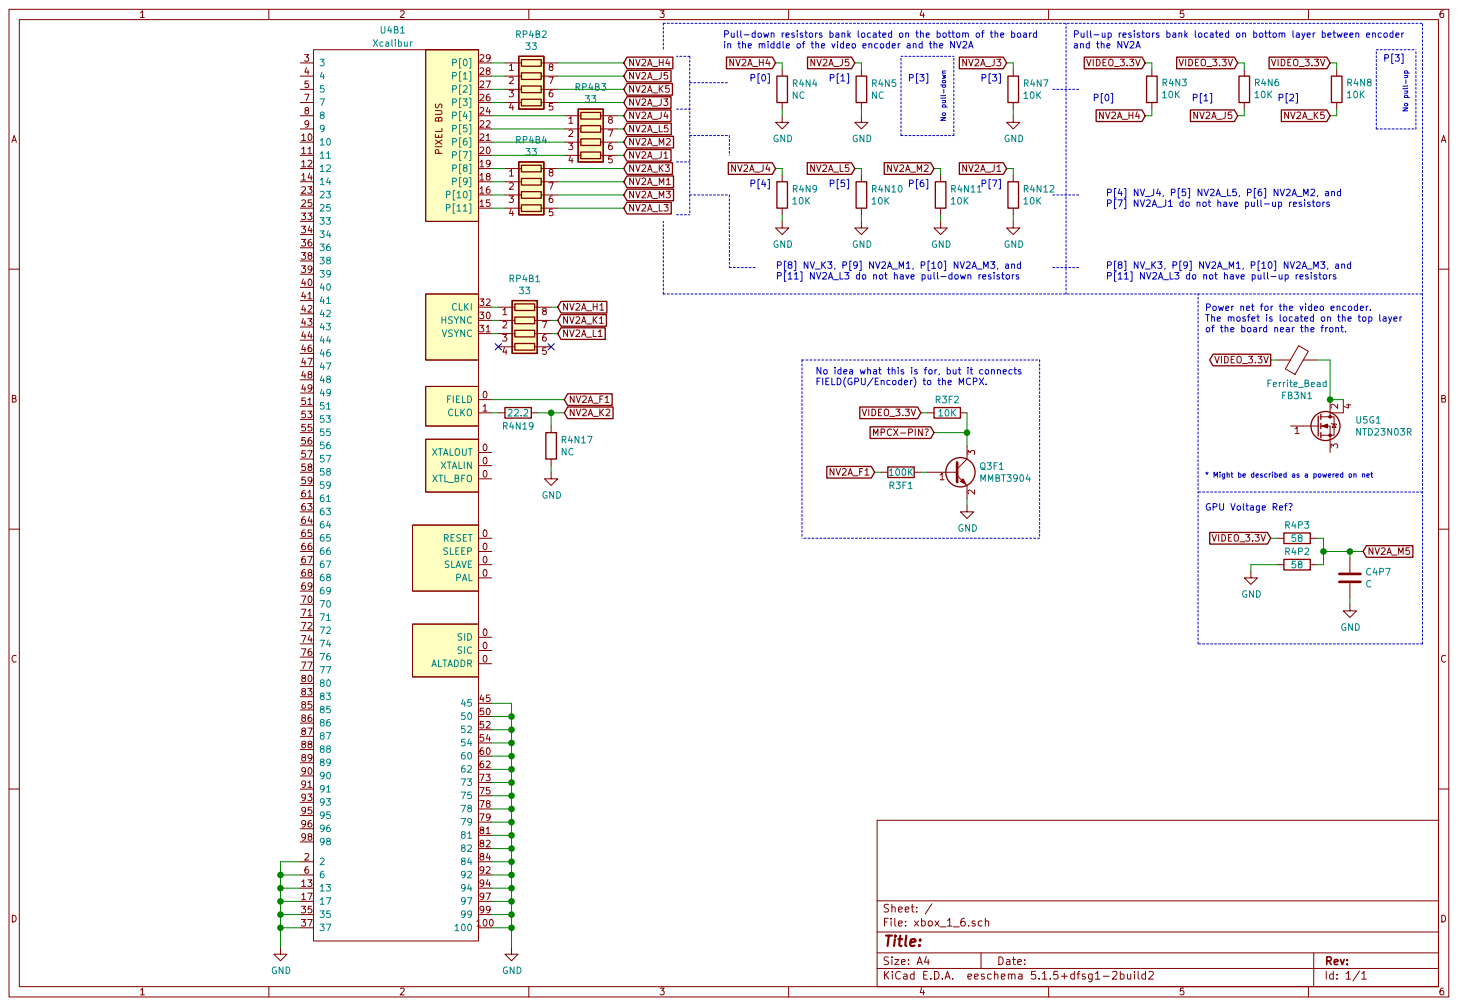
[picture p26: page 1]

Pull-down resistors bank located on the bottom of the board
in the middle of the video encoder and the NV2A

Pull-up resistors bank located on bottom layer between encoder and the NV2A

P[0] No idea what this is for, but it connects FIELD(GPU/Encoder) to the MCPX.

P[7] NV2A_J1 do not have pull-up resistors Power net for the video encoder. The mosfet is located on the top layer of the board near the front. * Might be described as a powered on net

P[8] NV_K3, P[9] NV2A_M1, P[10] NV2A_M3, and
P[11] NV2A_L3 do not have pull-down resistors

P[11] NV2A_L3 do not have pull-up resistors

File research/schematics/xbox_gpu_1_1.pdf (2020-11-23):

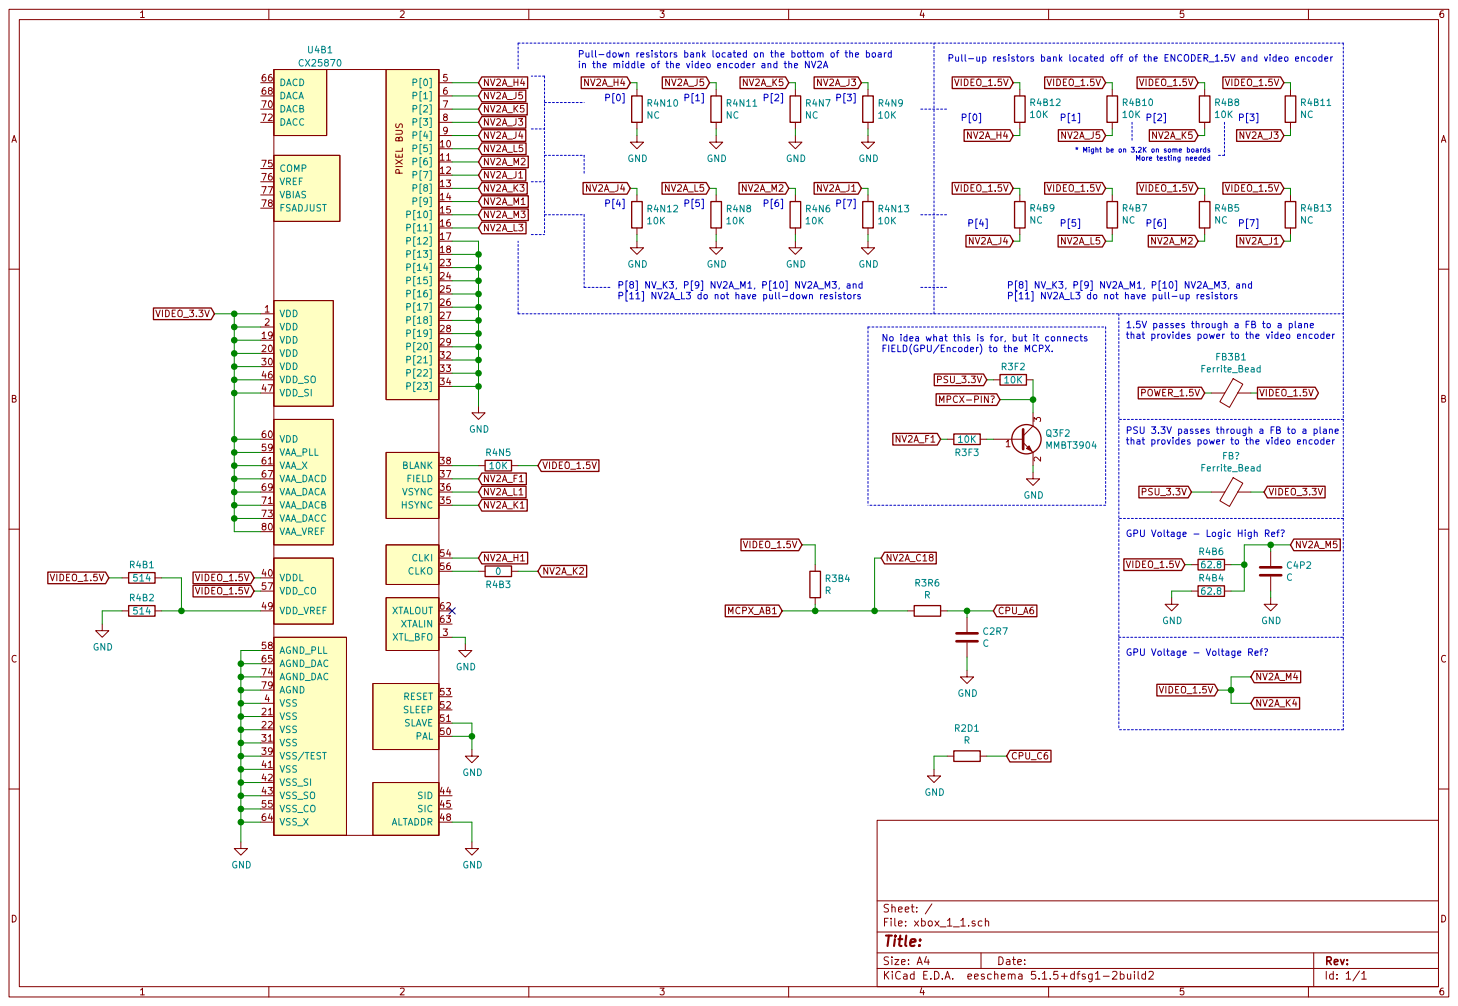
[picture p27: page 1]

P[1] Pull-down resistors bank located on the bottom of the board Pull-up resistors bank located off of the ENCODER_1.5V and video encoder 10K GND P[2] No idea what this is for, but it connects FIELD(GPU/Encoder) to the MCPX. 10K R4N13 P[6] * Might be on 3.2K on some boards More testing needed P[11] NV2A_L3 do not have pull-up resistors

in the middle of the video encoder and the NV2A

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

1.5V passes through a FB to a plane that provides power to the video encoder VIDEO_1.5V

PSU 3.3V passes through a FB to a plane
that provides power to the video encoder

GPU Voltage - Logic High Ref?

GPU Voltage - Voltage Ref?

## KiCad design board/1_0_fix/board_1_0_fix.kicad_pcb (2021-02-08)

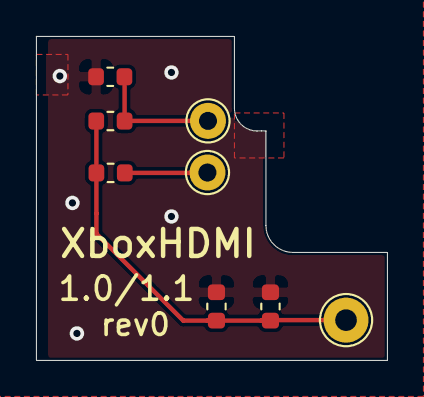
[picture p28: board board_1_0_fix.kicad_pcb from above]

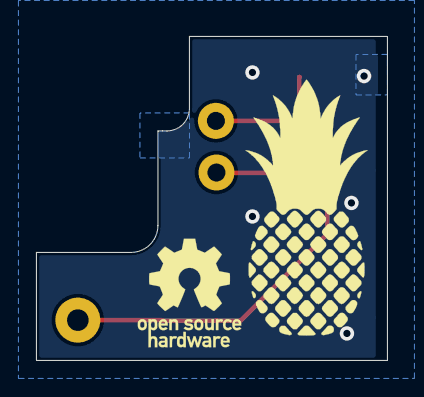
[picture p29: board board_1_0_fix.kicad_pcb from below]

Board: 2 copper layers, 19.5 x 18.0 mm, 10 parts (2 on the bottom side), 4 nets.

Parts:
C1, C2: C; C_0603_1608Metric
LOGO1: Logo_Open_Hardware_Small; OSHW-Logo_5.7x6mm_SilkScreen
LOGO2: C; logo
R4B7: 100; R_0603_1608Metric
R4M7, R4N14: 200; R_0603_1608Metric
TP1: TestPoint; TestPoint_THTPad_D2.5mm_Drill1.2mm
TP2, TP3: TestPoint; TestPoint_THTPad_D2.0mm_Drill1.0mm

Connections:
CLKI: R4M7.2, R4N14.1, TP3.1
FIELD: R4B7.2, TP2.1
GND: C1.2, C2.2, R4N14.2
VIDEO_1v5: C1.1, C2.1, R4B7.1, R4M7.1, TP1.1

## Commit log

2020-11-23 Add schematic for Xbox 1.1 GPU encoder section
2020-11-23 Add schematic for Xbox 1.6 GPU encoder section
2020-12-02 Fix jumper wires in Installation Manual
2021-02-08 Board 1 0 fix (#12)
    * Initial design
    Design rev 0 for the Xbox 1.0-1.1 fix
    * Fix board layout for production
    Small adjustments to layout for the production run of rev0
    [board_1_0_fix.kicad_pcb, board_1_0_fix.sch]
2021-02-08 Add links to 3D printable parts
2021-02-15 Add PCB layout image to the QSB manual
2021-02-17 Correct QSB graphic for CLKI pin
2021-02-20 Add 'HDTV AV/component cable' requirement to installation manual
2021-03-02 Remove HDTV cable requirement for testing BIOS patch in manual
2021-03-27 Fix kernel patch not sending correct encoder id
2021-03-31 Remove references to 1.8v wire in the 1.6 installation manual
2021-03-31 Remove reference to 1.8v wire in the 1.6 installation manual
2021-04-18 Fix GND point in QSB image
2021-09-07 Change installation photo for the HD+ guides to one of the HD+ board
2022-02-09 Add STL files for 3D printed parts
    Fusion360 removed the export links on project pages, so we'll have to host them here instead.
    [Board Spacer.stl, Case Filler.stl]
2022-06-04 Remove reference to 1v8 wire
2023-03-31 Add note about SDA/SCL wires for Stellar upgrade
